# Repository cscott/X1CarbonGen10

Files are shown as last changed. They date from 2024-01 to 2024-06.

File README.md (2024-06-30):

# Input Module for Thinkpad X1 Carbon Gen 10 keyboard
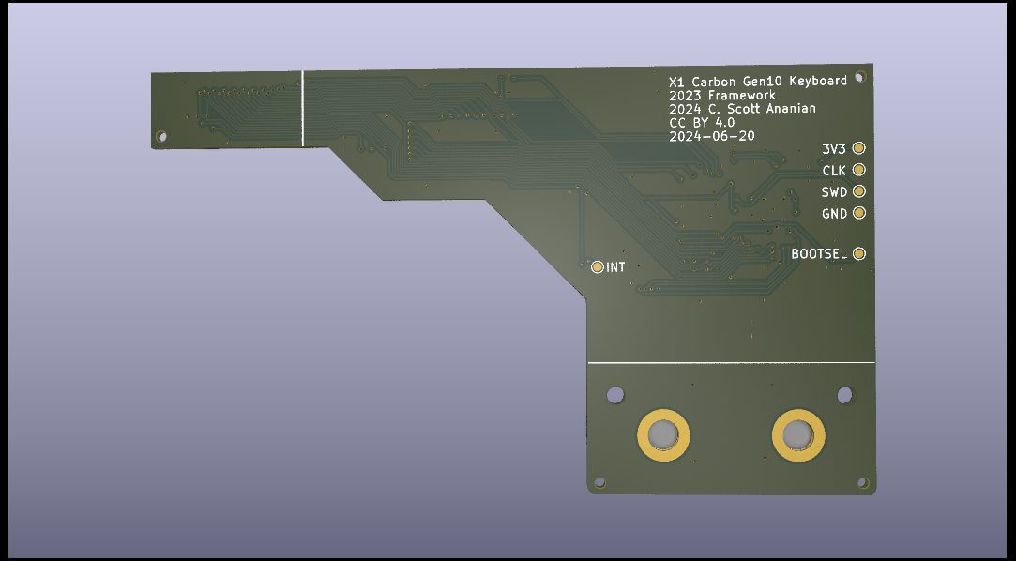
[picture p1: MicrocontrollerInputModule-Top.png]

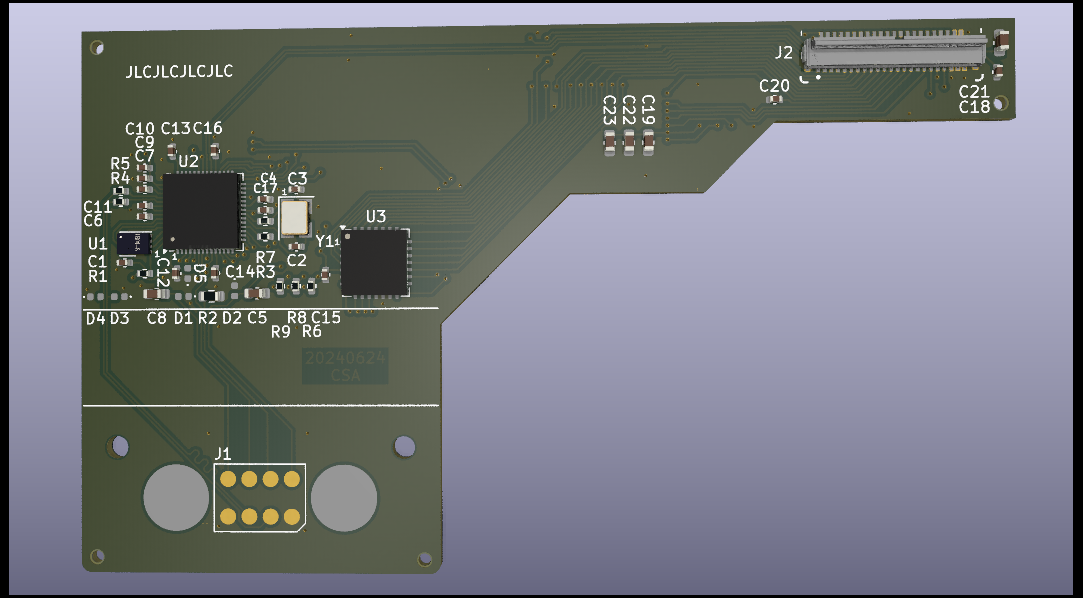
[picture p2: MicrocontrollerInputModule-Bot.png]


This module is based on the "Microcontroller Input Module" example
from https://github.com/FrameworkComputer/InputModules which in turn
is based on the Adafruit Feather RP2040 (https://www.adafruit.com/product/4884).

More discussion of this project, and of replacement keyboards for
the Framework 16 laptop generally, can be found in the [Framework
forums](https://community.frame.work/t/thinkpad-keyboard-mod-super-early-stages/38484/58).

## License
Input Modules © 2023 by Framework Computer Inc is licensed under CC BY 4.0.

This module for the Thinkpad X1 Carbon Gen 10 keyboard is © 2024 by
C. Scott Ananian and is also licensed under CC BY 4.0.

To view a copy of this license,
visit http://creativecommons.org/licenses/by/4.0/

## Fabrication and Assembly
A 0.8mm PCB is recommended.

All components are SMT on the bottom side of the board.

To enter boot mode on the RP2040 to reflash, hold down the "Fn" key on
the keyboard as power is applied.

## BOM
You can find alternatives for just about each of these components
except for the microcontroller.  The keyboard FPC is designed to be inserted
with contacts facing down toward the PCB, which is "up" (since the connector
is on the bottom side of the board) and thus will require folding the
keyboard's FPC cable to achieve the proper orientation.

Notes: 1uF caps are 2.2uF in pico reference design and it had one more 100nF cap on 1v1;
match crystal caps to crystal selected.

| Item # | Designator | Qty | Manufacturer | Mfg Part # | Description / Value | Package/Footprint | Type |
|---|---|-----|---|---|---|---|---|
| 1 | C1, C4, C6, C9, C11, C12, C13, C14, C15, C16, C17, C18, C20 | 13  | Samsung | CL05B104KO5NNNC | 100nF | Capacitor_SMD:C_0402_1005Metric | SMT  |
| 2 | C2, C3 | 2 | Murata | GRM1555C1H150JA01D | 15pF | Capacitor_SMD:C_0402_1005Metric | SMT  |
| 3 | C5, C8, C19, C21, C22, C23 | 6 | TDK | C1608X5R1A106M080AC | 10uF | Capacitor_SMD:C_0603_1608Metric | SMT  |
| 4 | C7, C10 | 2 | Samsung | CL05A105KO5NNNC | 1uF | Capacitor_SMD:C_0402_1005Metric | SMT  |
| 5 | D1, D2, D3, D4, D5 | 5 | Littelfuse | SP0402B-ULC-01ETG | D_TVS | Diode_SMD:D_0402_1005Metric | SMT  |
| 6 | H1, H2 | 2 | Keystone | 24929 | 24929 | InputModule:MountingHole_3.7mm_Pad_24929 | SMT  |
| 7 | J2 | 1 | HDGC | 0.3K-HX-45PWB | 45-pin FPC connector | 20655-045E-01:0.3K-HX-45PWB | SMT  |
| 8 | R1, R3 | 2 | Yageo | RC0402FR-071KL | 1k | Resistor_SMD:R_0402_1005Metric | SMT  |
| 9 | R2 | 1 | Yageo | RC0402FR-07330KL | 330k | Resistor_SMD:R_0402_1005Metric | SMT  |
| 10 | R4, R5 | 2 | Panasonic | ERJ-2RKF27R0X | 27 | Resistor_SMD:R_0402_1005Metric | SMT  |
| 11 | R6, R7, R8, R9 | 4 | Panasonic | ERJ-2RKF1000X | 100 | Resistor_SMD:R_0402_1005Metric | SMT  |
| 12 | U1 | 1 | Winbond | W25Q16JVUXIQ | W25Q16JVUXIQ | InputModule:SON-8-1EP_3x2mm_P0.5mm_EP0.2x1.6mm | SMT  |
| 13 | U2 | 1 | Raspberry Pi | RP2040TR7 | RP2040 | Package_DFN_QFN:QFN-56-1EP_7x7mm_P0.4mm_EP3.2x3.2mm  | SMT  |
| 14 | U3 | 1 | Microchip | MCP23S17_ML | MCP23S17_ML | Package_DFN_QFN:QFN-28-1EP_6x6mm_P0.65mm_EP4.25x4.25mm | SMT|
| 15 | Y1 | 1 | Abracon | ABM8G-12.000MHZ-18-D2Y-T | 12.000MHz | Crystal:Crystal_SMD_3225-4Pin_3.2x2.5mm | SMT  |

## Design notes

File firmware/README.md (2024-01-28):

Basic firmware examples for initial bring-up and testing, written
in Circuit Python.

First, install [Circuit Python 8.x for the Adafruit KB2040 board](https://circuitpython.org/downloads),
which is close enough hardware-wise to our board to work.

Then copy the `lib` and `kmk` directories from this directory to
the `CIRCUITPY` drive.  These are from the
[Adafruit CircuitPython bundle 8.x](https://circuitpython.org/libraries)
and from the
[KMK](https://github.com/KMKfw/kmk_firmware/blob/master/docs/en/Getting_Started.md)
project.

Then we have a number of different examples to try; for each just
copy the file to `code.py` on the `CIRCUITPY` drive:
* [`continuity.py`](./continuity.py):
  a basic continuity tester which was helpful in
  determining the initial keyboard matrix and keymap.
* [`ioexp.py`](./ioexp.py):
  some code for testing the IO expander and LEDs
* [`kmk.py`](./kmk.py):
  A basic keyboard implementation in CircuitPython using
  KMK. No trackpoint support (a limitation of KMK), the Fn key is
  not currently mapped (this could be done), and the MUTE and MICMUTE
  LEDs are not supported (a limitation of KMK?).

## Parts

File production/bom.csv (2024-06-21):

Designator | Footprint | Quantity | Value | LCSC Part #
C1, C11, C12, C13, C14, C15, C16, C17, C18, C20, C4, C6, C9 | 0402 | 13 | 100nF | C1525
C10, C7 | 0402 | 2 | 1uF | C52923
C19, C21, C22, C23, C5, C8 | 0603 | 6 | 10uF | C96446
C2, C3 | 0402 | 2 | 15pF | C1555
D1, D2, D3, D4, D5 | 0402 | 5 | D_TVS | C468904
J2 | 0.3K-HX-45PWB | 1 | 0.3K-HX-45PWB
R1, R3 | 0402 | 2 | 1k | C11702
R2 | 0603 | 1 | 330k | C23137
R4, R5 | 0402 | 2 | 27 | C138021
R6, R7, R8, R9 | 0402 | 4 | 100 | C25076
U1 | SON-8-1EP_3x2mm_P0.5mm_EP0.2x1.6mm | 1 | W25Q16JVUXIQ | C2843335
U2 | QFN-56-1EP_7x7mm_P0.4mm_EP3.2x3.2mm | 1 | RP2040 | C2040
U3 | QFN-28-1EP_6x6mm_P0.65mm_EP4.25x4.25mm | 1 | MCP23S17_ML | C629442
Y1 | Crystal_SMD_3225-4Pin_3.2x2.5mm | 1 | 12.000MHz | C9002

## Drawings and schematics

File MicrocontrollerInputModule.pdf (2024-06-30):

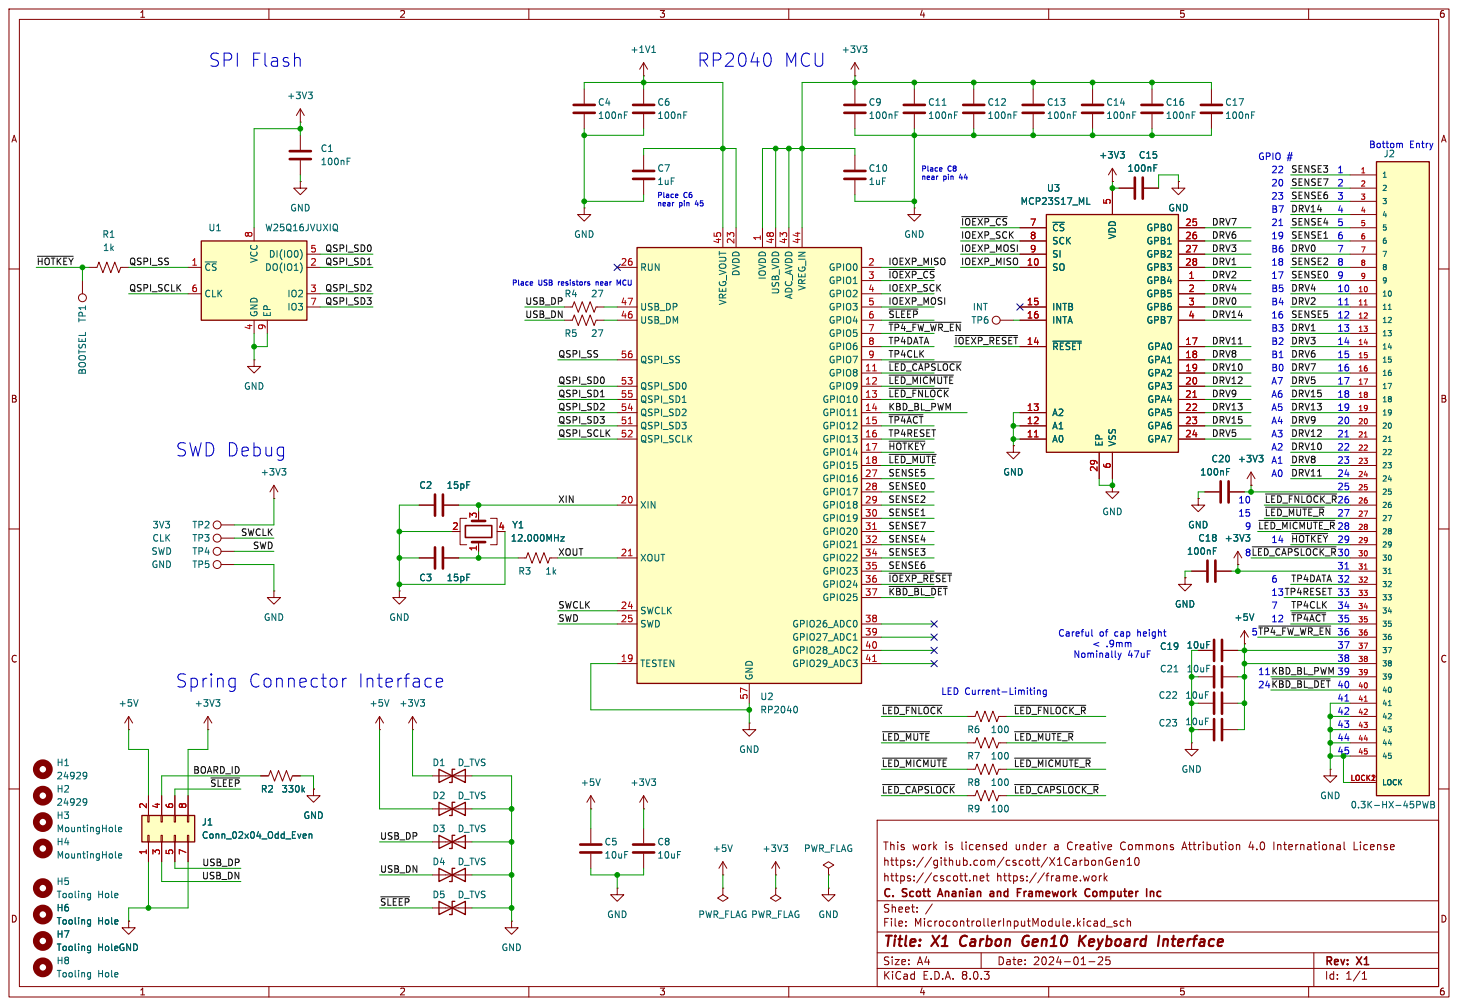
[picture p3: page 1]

1 GPIO8 11 GPIO9 12 GPIO10 13 GPIO11 14 GPIO12 15 GPIO13 16 GPIO14 17 GPIO15 18 TESTEN 19 GPIO0 2 XIN 20 XOUT 21 DVDD 23 SWCLK 24 SWD 25 RUN 26 GPIO16 27 GPIO17 28 GPIO18 29 GPIO1 3 GPIO19 30 GPIO20 31 GPIO21 32 GPIO22 34 GPIO23 35 GPIO24 36 GPIO25 37 GPIO26_ADC0 38 GPIO27_ADC1 39 GPIO2 4 GPIO28_ADC2 40 GPIO29_ADC3 41 ADC_AVDD 43 VREG_IN 44 VREG_VOUT 45 USB_DM 46 USB_DP 47 USB_VDD 48 GPIO3 5 QSPI_SD3 51 QSPI_SCLK 52 QSPI_SD0 53 QSPI_SD2 54 QSPI_SD1 55 QSPI_SS 56 GND 57 GPIO4 6 GPIO5 7 GPIO6 8 GPIO7 9 U2 RP2040 R5 27 +5V GND

17A4 Careful of cap height < .9mm

Id: 1/1 Title: X1 Carbon Gen10 Keyboard Interface

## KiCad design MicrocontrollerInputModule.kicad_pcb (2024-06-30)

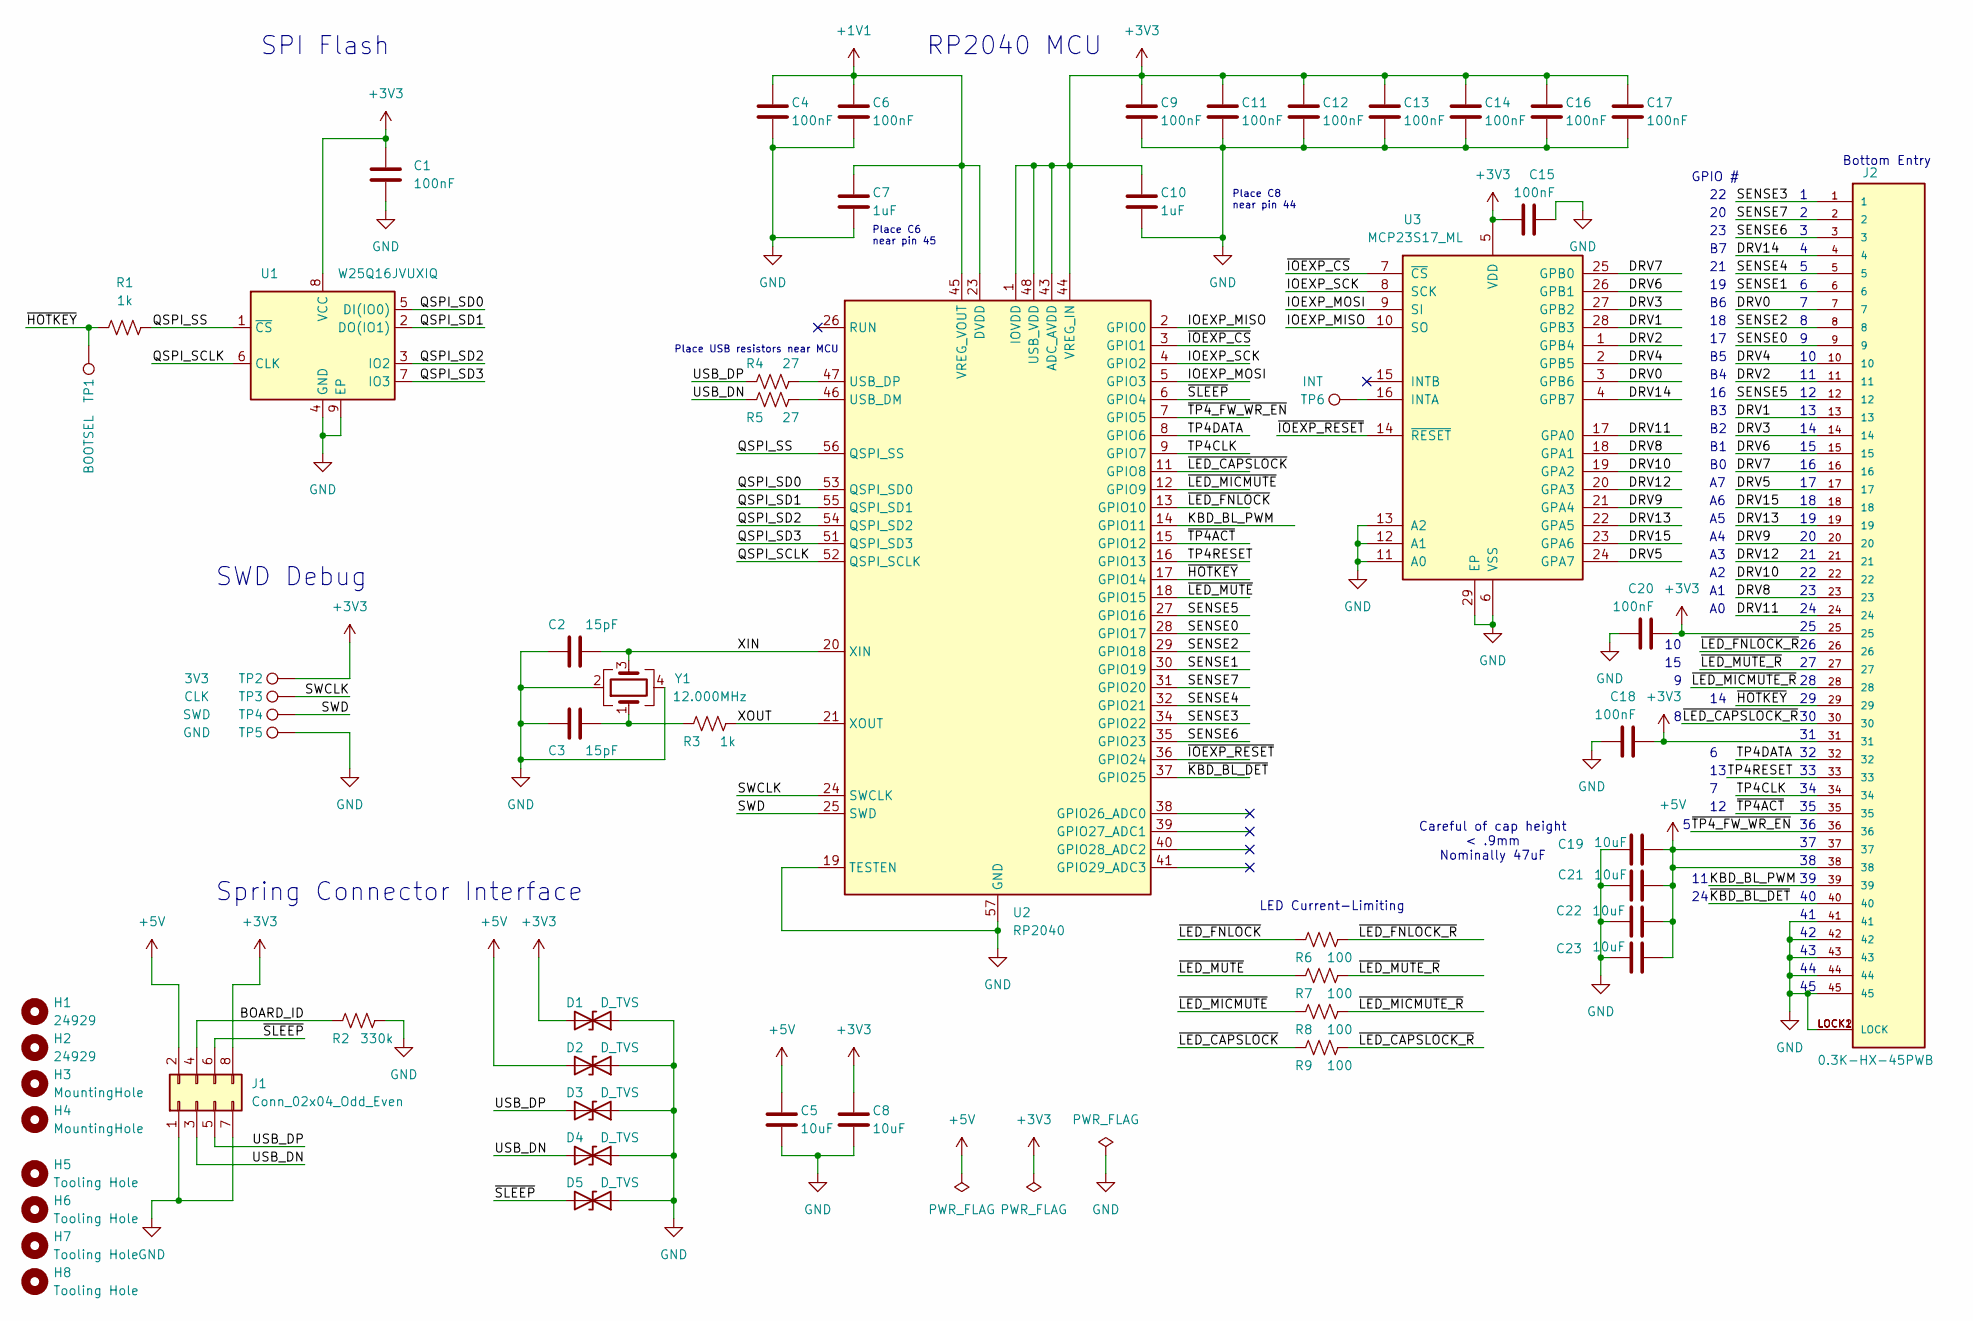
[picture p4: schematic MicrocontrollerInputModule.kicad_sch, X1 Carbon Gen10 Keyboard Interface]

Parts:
C1, C4, C6, C9, C11, C12, C13, C14, C15, C16, C17, C18, C20: 100nF; C_0402_1005Metric; LCSC C1525
C2, C3: 15pF; C_0402_1005Metric; LCSC C1555
C5, C8, C19, C21, C22, C23: 10uF; C_0603_1608Metric; LCSC C96446
C7, C10: 1uF; C_0402_1005Metric; LCSC C52923
D1, D2, D3, D4, D5: D_TVS; D_0402_1005Metric; LCSC C468904
H1, H2: 24929; MountingHole_3.7mm_Pad_24929; LCSC C5354888
H3, H4: MountingHole; MountingHole_2.1mm
H5, H6, H7, H8: Tooling Hole; JLCPCB Tooling Hole
J1: Conn_02x04_Odd_Even; PogoPads_2x4_P2.0mm
J2: 0.3K-HX-45PWB; PARTREV 5
R1, R3: 1k; R_0402_1005Metric; LCSC C11702
R2: 330k; R_0603_1608Metric; LCSC C23137
R4, R5: 27; R_0402_1005Metric; LCSC C138021
R6, R7, R8, R9: 100; R_0402_1005Metric; LCSC C25076
TP1: BOOTSEL; TestPoint_Pad_D1.0mm
TP2: 3V3; TestPoint_Pad_D1.0mm
TP3: CLK; TestPoint_Pad_D1.0mm
TP4: SWD; TestPoint_Pad_D1.0mm
TP5: GND; TestPoint_Pad_D1.0mm
TP6: INT; TestPoint_Pad_D1.0mm
U1: W25Q16JVUXIQ; SON-8-1EP_3x2mm_P0.5mm_EP0.2x1.6mm; LCSC C2843335
U2: RP2040; QFN-56-1EP_7x7mm_P0.4mm_EP3.2x3.2mm; LCSC C2040
U3: MCP23S17_ML; QFN-28-1EP_6x6mm_P0.65mm_EP4.25x4.25mm; LCSC C629442
Y1: 12.000MHz; Crystal_SMD_3225-4Pin_3.2x2.5mm; LCSC C9002

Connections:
+1V1: C4.1, C6.1, C7.1, U2.23 (DVDD), U2.45 (VREG_VOUT), U2.50 (DVDD)
+3V3: C1.1, C8.1, C9.1, C10.1, C11.1, C12.1, C13.1, C14.1, C15.1, C16.1, C17.1, C18.2, C20.2, D1.2 (A2), J1.8, J2.25, J2.31, TP2.1, U1.8 (VCC), U2.1 (IOVDD), U2.10 (IOVDD), U2.22 (IOVDD), U2.33 (IOVDD), U2.42 (IOVDD), U2.43 (ADC_AVDD), U2.44 (VREG_IN), U2.48 (USB_VDD), U2.49 (IOVDD), U3.5 (VDD)
+5V: C5.1, C19.2, C21.2, C22.2, C23.2, D2.2 (A2), J1.2, J2.37, J2.38
/BOARD_ID: J1.4, R2.1
/DRV0: J2.7, U3.3 (GPB6)
/DRV1: J2.13, U3.28 (GPB3)
/DRV2: J2.11, U3.1 (GPB4)
/DRV3: J2.14, U3.27 (GPB2)
/DRV4: J2.10, U3.2 (GPB5)
/DRV5: J2.17, U3.24 (GPA7)
/DRV6: J2.15, U3.26 (GPB1)
/DRV7: J2.16, U3.25 (GPB0)
/DRV8: J2.23, U3.18 (GPA1)
/DRV9: J2.20, U3.21 (GPA4)
/DRV10: J2.22, U3.19 (GPA2)
/DRV11: J2.24, U3.17 (GPA0)
/DRV12: J2.21, U3.20 (GPA3)
/DRV13: J2.19, U3.22 (GPA5)
/DRV14: J2.4, U3.4 (GPB7)
/DRV15: J2.18, U3.23 (GPA6)
/IOEXP_MISO: U2.2 (GPIO0), U3.10 (SO)
/IOEXP_MOSI: U2.5 (GPIO3), U3.9 (SI)
/IOEXP_SCK: U2.4 (GPIO2), U3.8 (SCK)
/KBD_BL_PWM: J2.39, U2.14 (GPIO11)
/QSPI_SCLK: U1.6 (CLK), U2.52 (QSPI_SCLK)
/QSPI_SD0: U1.5 (DI(IO0)), U2.53 (QSPI_SD0)
/QSPI_SD1: U1.2 (DO(IO1)), U2.55 (QSPI_SD1)
/QSPI_SD2: U1.3 (IO2), U2.54 (QSPI_SD2)
/QSPI_SD3: U1.7 (IO3), U2.51 (QSPI_SD3)
/QSPI_SS: R1.2, U1.1 (~CS), U2.56 (QSPI_SS)
/SENSE0: J2.9, U2.28 (GPIO17)
/SENSE1: J2.6, U2.30 (GPIO19)
/SENSE2: J2.8, U2.29 (GPIO18)
/SENSE3: J2.1, U2.34 (GPIO22)
/SENSE4: J2.5, U2.32 (GPIO21)
/SENSE5: J2.12, U2.27 (GPIO16)
/SENSE6: J2.3, U2.35 (GPIO23)
/SENSE7: J2.2, U2.31 (GPIO20)
/SWCLK: TP3.1, U2.24 (SWCLK)
/SWD: TP4.1, U2.25 (SWD)
/TP4CLK: J2.34, U2.9 (GPIO7)
/TP4DATA: J2.32, U2.8 (GPIO6)
/TP4RESET: J2.33, U2.16 (GPIO13)
/USB_DN: D4.2 (A2), J1.3, R5.1
/USB_DP: D3.2 (A2), J1.5, R4.1
/XIN: C2.2, U2.20 (XIN), Y1.3
/XOUT: R3.2, U2.21 (XOUT)
/~HOTKEY: J2.29, R1.1, TP1.1, U2.17 (GPIO14)
/~IOEXP_CS: U2.3 (GPIO1), U3.7 (~CS)
/~IOEXP_RESET: U2.36 (GPIO24), U3.14 (~RESET)
/~KBD_BL_DET: J2.40, U2.37 (GPIO25)
/~LED_CAPSLOCK_R: J2.30, R9.2
/~LED_CAPSLOCK: R9.1, U2.11 (GPIO8)
/~LED_FNLOCK_R: J2.26, R6.2
/~LED_FNLOCK: R6.1, U2.13 (GPIO10)
/~LED_MICMUTE_R: J2.28, R8.2
/~LED_MICMUTE: R8.1, U2.12 (GPIO9)
/~LED_MUTE_R: J2.27, R7.2
/~LED_MUTE: R7.1, U2.18 (GPIO15)
/~SLEEP: D5.2 (A2), J1.6, U2.6 (GPIO4)
/~TP4ACT: J2.35, U2.15 (GPIO12)
/~TP4_FW_WR_EN: J2.36, U2.7 (GPIO5)
GND: C1.2, C2.1, C3.1, C4.2, C5.2, C6.2, C7.2, C8.2, C9.2, C10.2, C11.2, C12.2, C13.2, C14.2, C15.2, C16.2, C17.2, C18.1, C19.1, C20.1, C21.1, C22.1, C23.1, D1.1 (A1), D2.1 (A1), D3.1 (A1), D4.1 (A1), D5.1 (A1), J1.1, J1.7, J2.41, J2.42, J2.43, J2.44, J2.45, J2.LOCK1 (LOCK), J2.LOCK2 (LOCK), R2.2, TP5.1, U1.4 (GND), U1.9 (EP), U2.19 (TESTEN), U2.57 (GND), U3.6 (VSS), U3.11 (A0), U3.12 (A1), U3.13 (A2), U3.29 (EP), Y1.2, Y1.4
unnamed: C3.2, R3.1, Y1.1
unnamed: R5.2, U2.46 (USB_DM)
unnamed: R4.2, U2.47 (USB_DP)
unnamed: TP6.1, U3.16 (INTA)

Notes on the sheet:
SPI Flash
Bottom Entry
LED Current-Limiting
Place C8 near pin 44
GPIO #
Place USB resistors near MCU
Spring Connector Interface
Place C6 near pin 45
RP2040 MCU
Careful of cap height < .9mm Nominally 47uF
SWD Debug

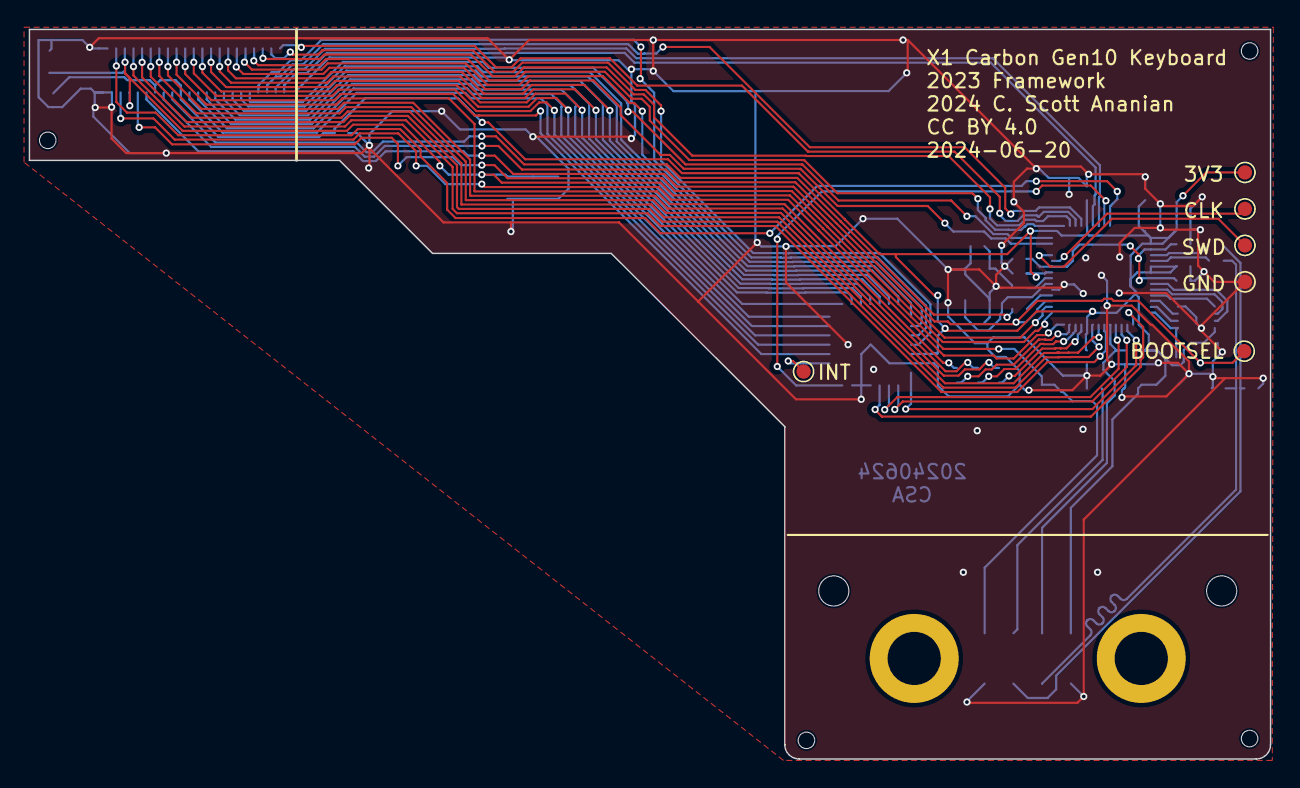
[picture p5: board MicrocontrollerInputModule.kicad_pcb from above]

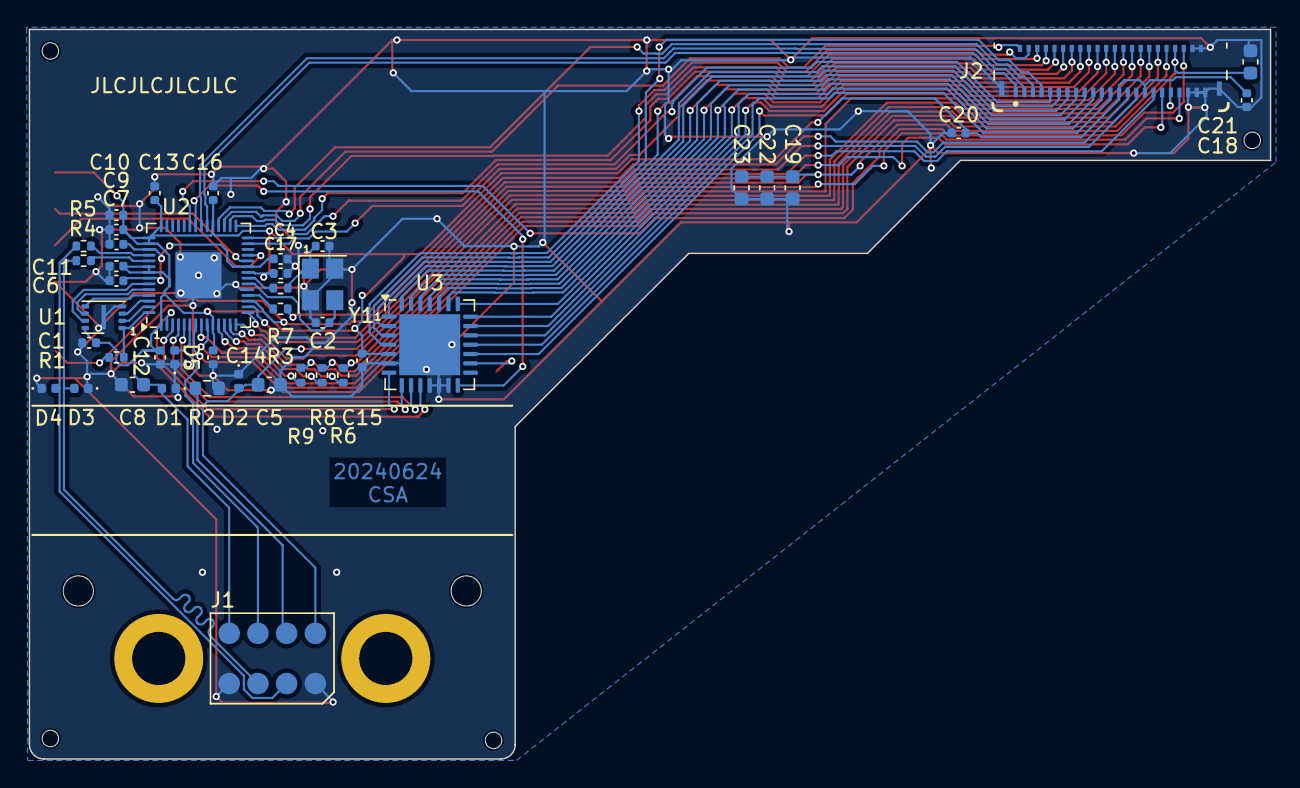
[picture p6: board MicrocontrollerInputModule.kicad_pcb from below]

Board: 2 copper layers, 86.4 x 50.8 mm, 57 parts (45 on the bottom side), 67 nets.

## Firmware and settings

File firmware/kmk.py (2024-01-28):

print("Starting")

import microcontroller
import board
import digitalio
import busio
import time
from adafruit_mcp230xx.mcp23017 import MCP23017

from keypad import Event as KeyEvent
from kmk.kmk_keyboard import KMKKeyboard
from kmk.scanners import Scanner
from kmk.scanners.keypad import KeysScanner
from kmk.keys import KC
from kmk.extensions.lock_status import LockStatus

i2c = busio.I2C(microcontroller.pin.GPIO1, microcontroller.pin.GPIO0)
ioexp_reset = digitalio.DigitalInOut(microcontroller.pin.GPIO2)
ioexp_reset.switch_to_output(False)
time.sleep(0.05)
ioexp_reset.switch_to_output(True)
time.sleep(0.05)
mcp = MCP23017(i2c)

class MyScanner(Scanner):
    def __init__(self):
        self.drv = [None] * 16
        for ionum, p in enumerate([
                11, 8, 10, 12, 9, 13, 15, 5,
                7, 6, 3, 1, 2, 4, 0, 14
        ]):
            self.drv[p] = mcp.get_pin(ionum)
            self.drv[p].switch_to_input(pull=digitalio.Pull.UP)
        self.sense = [None] * 8
        for ionum, p in enumerate([ 5, 0, 2, 1, 7, 4, 3, 6 ]):
            pin = getattr(microcontroller.pin, 'GPIO' + str(16 + ionum))
            self.sense[p] = digitalio.DigitalInOut(pin)
            self.sense[p].switch_to_input(pull=digitalio.Pull.UP)
        self.len_rows = len(self.drv)
        self.len_cols = len(self.sense)
        self._key_count = self.len_rows * self.len_cols
        initial_state_value = b'\x01'
        self.state = bytearray(initial_state_value) * self._key_count
        self.offset = 0

    @property
    def key_count(self):
        return self._key_count

    def scan_for_changes(self):
        '''
        Poll the matrix for changes and return either None (if nothing updated)
        or a bytearray (reused in later runs so copy this if you need the raw
        array itself for some crazy reason) consisting of (row, col, pressed)
        which are (int, int, bool)
        '''
        ba_idx = 0
        any_changed = False

        for oidx, opin in enumerate(self.drv):
            opin.switch_to_output(False)

            for iidx, ipin in enumerate(self.sense):
                # cast to int to avoid
                #
                # >>> xyz = bytearray(3)
                # >>> xyz[2] = True
                # Traceback (most recent call last):
                #   File "<stdin>", line 1, in <module>
                # OverflowError: value would overflow a 1 byte buffer
                #
                # I haven't dived too far into what causes this, but it's
                # almost certainly because bool types in Python aren't just
                # aliases to int values, but are proper pseudo-types
                new_val = int(ipin.value)
                old_val = self.state[ba_idx]

                if old_val != new_val:
                    row = oidx
                    col = iidx

                    pressed = not new_val # active low
                    self.state[ba_idx] = new_val

                    any_changed = True
                    break

                ba_idx += 1

            opin.switch_to_input(pull=digitalio.Pull.UP)
            if any_changed:
                break

        if any_changed:
            key_number = self.len_cols * row + col + self.offset
            return KeyEvent(key_number, pressed)

class MyKeyboard(KMKKeyboard):
    def __init__(self):
        self.matrix = [
            MyScanner(),
            KeysScanner(
                pins=[ microcontroller.pin.GPIO14 ], # HOTKEY
                value_when_pressed = False,
                pull = True
            )
        ]
        self.keymap = [
            [
                # DRV0
                KC.GRAVE, KC.N1, KC.Q, KC.TAB, KC.A, KC.ESCAPE, KC.Z, KC.NO,
                # DRV1
                KC.F1, KC.N2, KC.W, KC.CAPSLOCK, KC.S, KC.NO, KC.X, KC.NO,
                # DRV2
                KC.F2, KC.N3, KC.E, KC.F3, KC.D, KC.F4, KC.C, KC.NO,
                # DRV3
                KC.N5, KC.N4, KC.R, KC.T, KC.F, KC.G, KC.V, KC.B,
                # DRV4
                KC.N6, KC.N7, KC.U, KC.Y, KC.J, KC.H, KC.M, KC.N,
                # DRV5
                KC.EQUAL, KC.N8, KC.I, KC.RBRACKET, KC.K, KC.F6, KC.COMMA, KC.NO,
                # DRV6
                KC.F8, KC.N9, KC.O, KC.F7, KC.L, KC.NO, KC.DOT, KC.NO,
                # DRV7
                KC.MINUS, KC.N0, KC.P, KC.LBRACKET, KC.SCOLON, KC.QUOTE, KC.NO, KC.SLASH,
                # DRV8
                KC.F9, KC.F10, KC.NO, KC.BSPACE, KC.BSLASH, KC.F5, KC.ENTER, KC.SPACE,
                # DRV9
                KC.INSERT, KC.F12, KC.NO, KC.LGUI, KC.NO, KC.NO, KC.NO, KC.RIGHT,
                # DRV10
                KC.DELETE, KC.F11, KC.NO, KC.NO, KC.NO, KC.NO, KC.NO, KC.DOWN,
                # DRV11
                KC.PGUP, KC.PGDOWN, KC.NO, KC.NO, KC.NO, KC.NO, KC.NO, KC.NO,
                # DRV12
                KC.HOME, KC.END, KC.NO, KC.NO, KC.NO, KC.UP, KC.NO, KC.LEFT,
                # DRV13
                KC.NO, KC.PSCREEN, KC.NO, KC.NO, KC.NO, KC.LALT, KC.NO, KC.RALT,
                # DRV14
                KC.NO, KC.NO, KC.NO, KC.LSHIFT, KC.NO, KC.NO, KC.RSHIFT, KC.NO,
                # DRV15
                KC.LCTRL, KC.NO, KC.NO, KC.NO, KC.NO, KC.NO, KC.RCTRL, KC.NO
            ],
        ]

capslock = digitalio.DigitalInOut(microcontroller.pin.GPIO8)
capslock.switch_to_output(True)
class LEDLockStatus(LockStatus):
    def set_lock_leds(self):
        capslock.value = not self.get_caps_lock()
    def after_hid_send(self, sandbox):
        super().after_hid_send(sandbox)  # Critically important. Do not forget
        if self.report_updated:
            self.set_lock_leds()

keyboard = MyKeyboard()
keyboard.extensions.append(LEDLockStatus())

if __name__ == '__main__':
    keyboard.go()

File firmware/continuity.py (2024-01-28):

# SPDX-FileCopyrightText: 2024 C. Scott Ananian
#
# SPDX-License-Identifier: MIT

"""CircuitPython Essentials Pin Map Script"""
import microcontroller
import board
import digitalio
import time

all_pins = dict()
for pin in dir(microcontroller.pin):
    p = getattr(microcontroller.pin, pin)
    if isinstance(p, microcontroller.Pin):
        d = digitalio.DigitalInOut(p)
        d.switch_to_input(pull=digitalio.Pull.UP)
        num = int(pin[4:])
        all_pins[num] = d


def check_one():
    # reset state for safety's sake
    for pin, d in all_pins.items():
        d.switch_to_input(pull=digitalio.Pull.UP)
    for pin, d in all_pins.items():
        # set just this pin high
        d.switch_to_output(False)
        for pin2, d2 in all_pins.items():
            if pin > pin2 and d2.value == False:
                print(pin2, "connected to", pin)
        d.switch_to_input(pull=digitalio.Pull.UP)

while True:
    print("----")
    check_one()
    time.sleep(0.5)

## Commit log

2023-03-12 Rename to Microcontroller Input Module
    [MicrocontrollerInputModule.kicad_pro.kicad_pcb, MicrocontrollerInputModule.kicad_pro.kicad_sch]
2023-03-12 Rename again.
    [MicrocontrollerInputModule.kicad_pcb, MicrocontrollerInputModule.kicad_sch]
2023-03-12 Fix some footprints
    [MicrocontrollerInputModule.kicad_pcb]
2024-01-25 Initial reconfiguration for X1 Carbon Gen10 Keyboard module
    RP2040 pin assignments are somewhat arbitrary; PCB is not yet routed;
    position of framework input module connector is also arbitrary.
    [MicrocontrollerInputModule.kicad_pcb, MicrocontrollerInputModule.kicad_sch]
2024-01-26 First complete version, fully routed
    [MicrocontrollerInputModule.kicad_pcb, MicrocontrollerInputModule.kicad_sch]
2024-01-26 Renumber components, tidy up silkscreen
    [MicrocontrollerInputModule.kicad_pcb, MicrocontrollerInputModule.kicad_sch]
2024-01-26 Update README; change C19 to an 0603 cap; improve ground plane connectivity
    [MicrocontrollerInputModule.kicad_pcb, MicrocontrollerInputModule.kicad_sch]
2024-01-28 Add some basic firmware for this keyboard, implemented in CircuitPython
2024-01-28 Swap TP4CLK and TP4DATA to handle PIO requirements
    The current RP2040 PS/2 driver in:
    https://github.com/qmk/qmk_firmware/blob/master/platforms/chibios/drivers/vendor/RP/RP2040/ps2_vendor.c#L24
    requires that PS2_DATA_PIN is the one *before* PS2_CLOCK_PIN, so swap our
    GPIO assignments to match.
    [MicrocontrollerInputModule.kicad_pcb, MicrocontrollerInputModule.kicad_sch]
2024-01-29 Switch to 23S17 from 23017
    This increases the scan rate by ~5x (from 1.7MHz clock to 10MHz) and also
    works around an erratum (?) in the 23017 which forces the A7 and B7 gpios
    to be outputs. This could lead to a short circuit if (for example)
    a key on the same SENSE line is held down in both the A7 and some other
    row -- A7 would be driven high (because it can't be three-stated) while
    the other row is driven low, and a direct connection exists through
    the two key switches.
    The 23S17 part requires a few extra I/O pins, but we have some to spare.
    Disconnected the INT pin from the I/O expander, because the way we would
    do an interrupt is by driving all low on the 23S17 pins and then watching
    fo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
    [MicrocontrollerInputModule.kicad_pcb, MicrocontrollerInputModule.kicad_sch]
2024-01-29 Update with BOM information
    [MicrocontrollerInputModule.kicad_pcb, MicrocontrollerInputModule.kicad_sch]
2024-01-29 Add footprint for an alternative FPC connector (stocked by JLCPCB)
    We're not going to switch our design to use this yet, but it's here for
    future use.
2024-01-29 Version sent to JLCPCB for assembly 2024-01-29
    [MicrocontrollerInputModule.kicad_pcb, MicrocontrollerInputModule.kicad_sch]
2024-01-31 Update renderings of the board
2024-06-19 Last kicad v7 version
2024-06-20 kicad v8
    [MicrocontrollerInputModule.kicad_pcb, MicrocontrollerInputModule.kicad_sch]
2024-06-20 Size test for relocating the FPC connector
    [MicrocontrollerInputModule.kicad_pcb, MicrocontrollerInputModule.kicad_sch]
2024-06-21 Update to use new FPC connector and position, fix sense resistor, etc
    [MicrocontrollerInputModule.kicad_pcb, MicrocontrollerInputModule.kicad_sch]
2024-06-21 Second version sent to JLCPCB
    [MicrocontrollerInputModule.kicad_pcb, MicrocontrollerInputModule.kicad_sch, bom.csv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]
2024-06-29 Documentation and 3d model updates
    [MicrocontrollerInputModule.kicad_pcb]
2024-06-30 Update 3d models
    [MicrocontrollerInputModule.kicad_pcb, MicrocontrollerInputModule.kicad_sch]
2024-06-30 Adjust board thickness to 0.8mm
    [MicrocontrollerInputModule.kicad_pcb]

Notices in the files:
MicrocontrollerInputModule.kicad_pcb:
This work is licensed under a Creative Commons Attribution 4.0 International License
